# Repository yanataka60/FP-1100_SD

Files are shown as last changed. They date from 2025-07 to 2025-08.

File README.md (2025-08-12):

# CASIO FP-1100にSD-Cardとのロード、セーブ機能

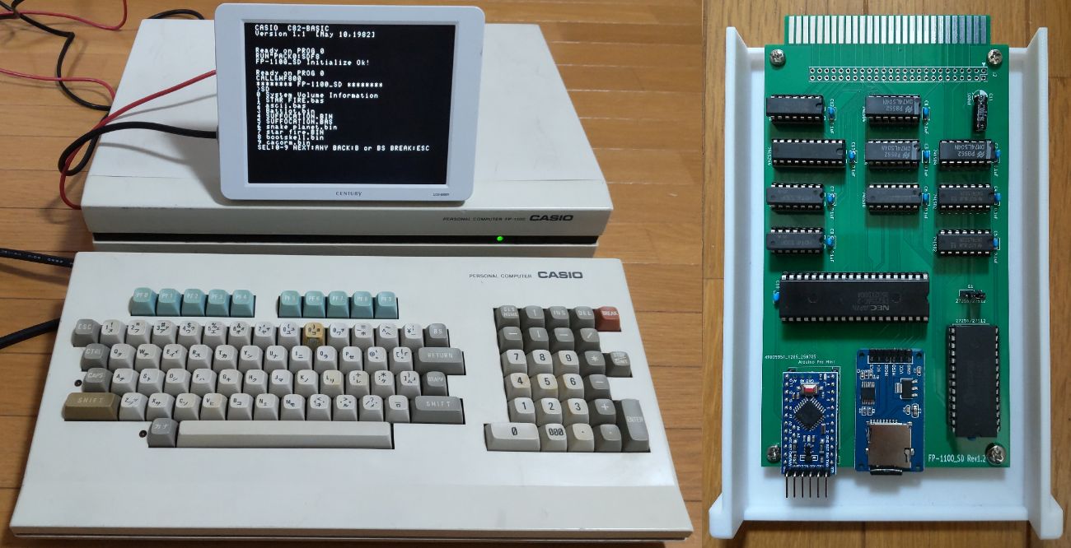
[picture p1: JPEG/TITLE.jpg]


　CASIO FP-1100でCMTの代わりにSD-CARDからロード、セーブを実現するものです。

　FP-1000は所有していないので試していませんが、動作すると思います。

　SDから読み込めるCMTのファイル形式はEMUで一般的なWAV、CASには対応していません。bugfire2009さんのDumpListEditorを使ってバイナリ形式に変換したものを使います。

　機械語 -> 各モデル固有ヘッダ付きBINファイル、拡張子は.bin

　BASIC -> BASファイル、拡張子は.bas

　CMTからの読み込み実行に数分掛かっていたゲームも数十秒で実行できます。

　ただし、CMT用プログラムのすべてがSD対応となるわけではありません。特に市販ゲームはCMT読み込みに独自ルーチンを使っているものもあるため、SD対応は不明です。

　なお、Arduino、ROMへ書き込むための機器が別途必要となります。

## 回路図
　KiCadフォルダ内のFP-1100_SD.PDFを参照してください。

[回路図](https://github.com/yanataka60/FP-1100_SD/blob/main/Kicad/FP-1100_SD.PDF)

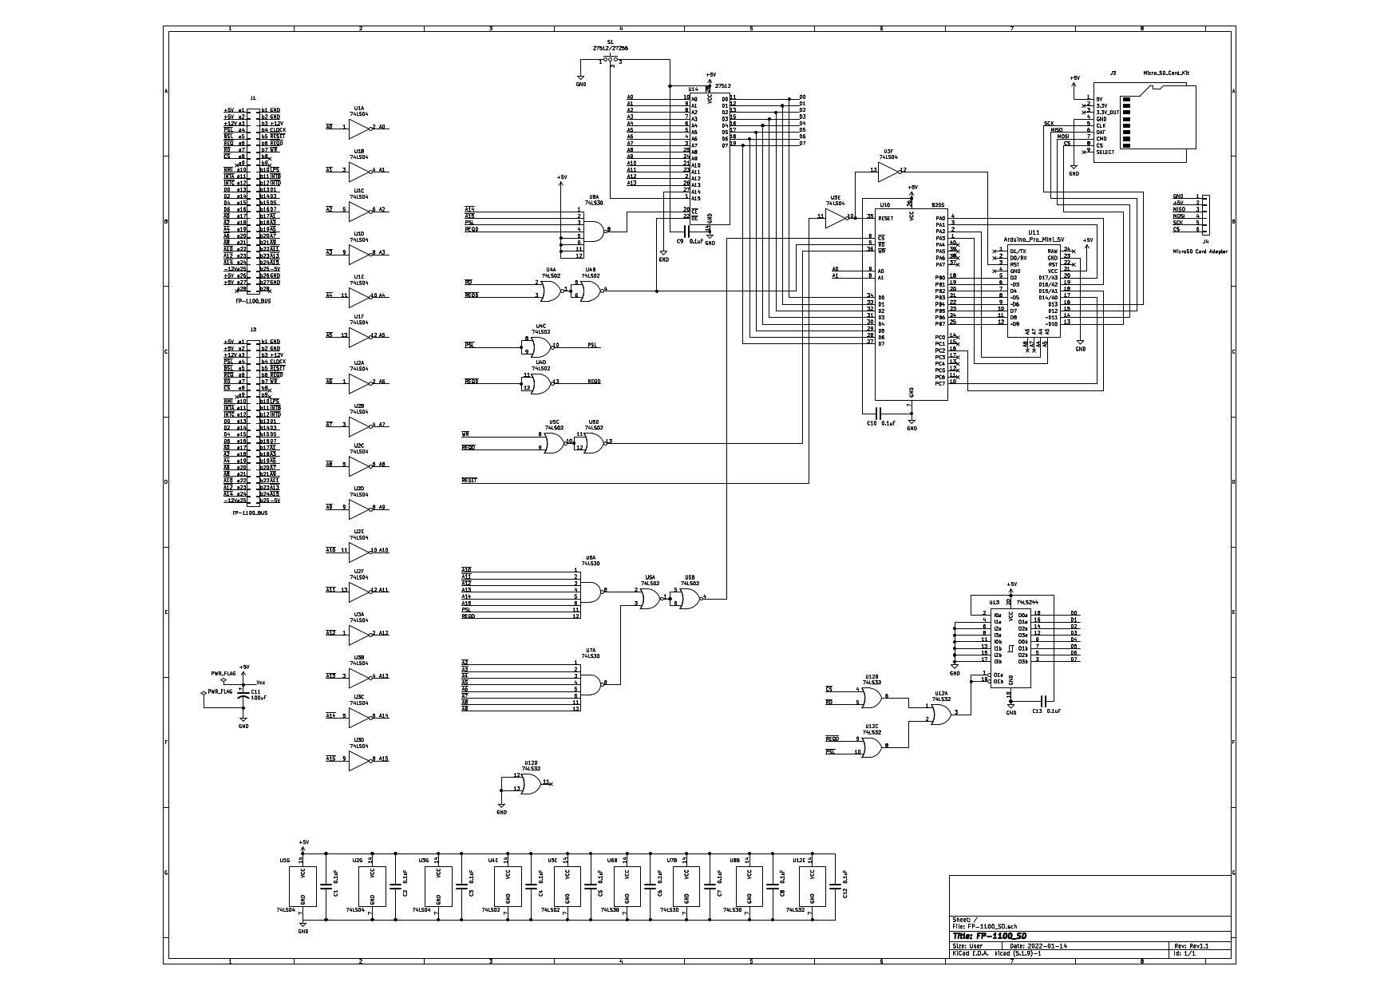
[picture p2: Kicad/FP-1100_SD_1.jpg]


## 部品
|番号|品名|数量|備考|
| --- | --- | --- | --- |
||J3,J4のいずれか|||
|J3|Micro_SD_Card_Kit|1|秋月電子通商 AE-microSD-LLCNV (注1)|
|J4|MicroSD Card Adapter|1|Arduino等に使われる5V電源に対応したもの(注2)|
|U1-U3|74LS04|3||
|U4-U5|74LS02|2||
|U6-U8|74LS30|3||
|U10|8255|1||
|U11|Arduino_Pro_Mini_5V|1|Atmega328版を使用 168版は不可。(注3)|
|U12|74LS32|1||
|U13|74LS244|1||
|U14|ROM 27256/29C256又は27512/27C512相当品|1|入手しやすいものでOK、28C256は不可|
|C1-C10,C12,C13|積層セラミックコンデンサ 0.1uF|12||
|C11|電解コンデンサ 16v100uF|1||
|S1|3Pin ピンヘッダーとジャンパーピン又は3Pスライドスイッチ|1|秋月電子通商 SS12D01G4など|

### 注1)秋月電子通商　AE-microSD-LLCNVのJ1ジャンパはショートしてください。

### 注2)MicroSD Card Adapterを使う場合

J4に取り付けます。

MicroSD Card Adapterについているピンヘッダを除去してハンダ付けするのが一番確実ですが、J2の穴にMicroSD Card Adapterをぴったりと押しつけ、裏から多めにハンダを流し込むことでハンダ付けをする方法もあります。なお、この方法の時にはしっかりハンダ付けが出来たかテスターで導通を確認しておいた方が安心です。

ハンダ付けに自信のない方はJ1の秋月電子通商　AE-microSD-LLCNVをお使いください。AE-microSD-LLCNVならパワーLED、アクセスLEDが付いています。

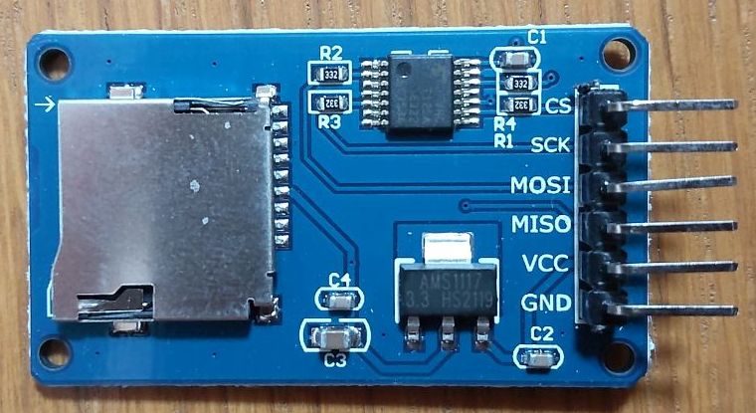
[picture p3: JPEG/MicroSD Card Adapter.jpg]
MicroSD Card Adapter1


### 注3)Arduino Pro MiniはA4、A5ピンも使っています。

## FP-1100_SDをスロットに入れずに外付けとして使いたい場合のみ
　J2ピンヘッダを取り付けます。また、スロットからケーブルを引き出す基板が必要ですのでFP-1100_SD基板がもう一枚必要です。

|番号|品名|数量|備考|
| --- | --- | --- | --- |
|J2|2x25Pinコネクタ|1|秋月電子通商 PH-2x40SGなど|
||FP-1100_SD基板|1||
||2.54mmピッチ2x25Pinフラットケーブル|1|FP-1100の拡張スロットは2x28Pinですが、2x25Pinが使えます|

## 取り付け
　FP-1100本体後ろのスロットに挿入します。

　スロットにガイド等が無いためスロットの奥を覗き込みながら挿入します。

　基板の下に10～12mmの隙間が空くようにネジやスペーサーなどを取り付け、カードエッジコネクタと高さを合わせると挿入しやすくなります。

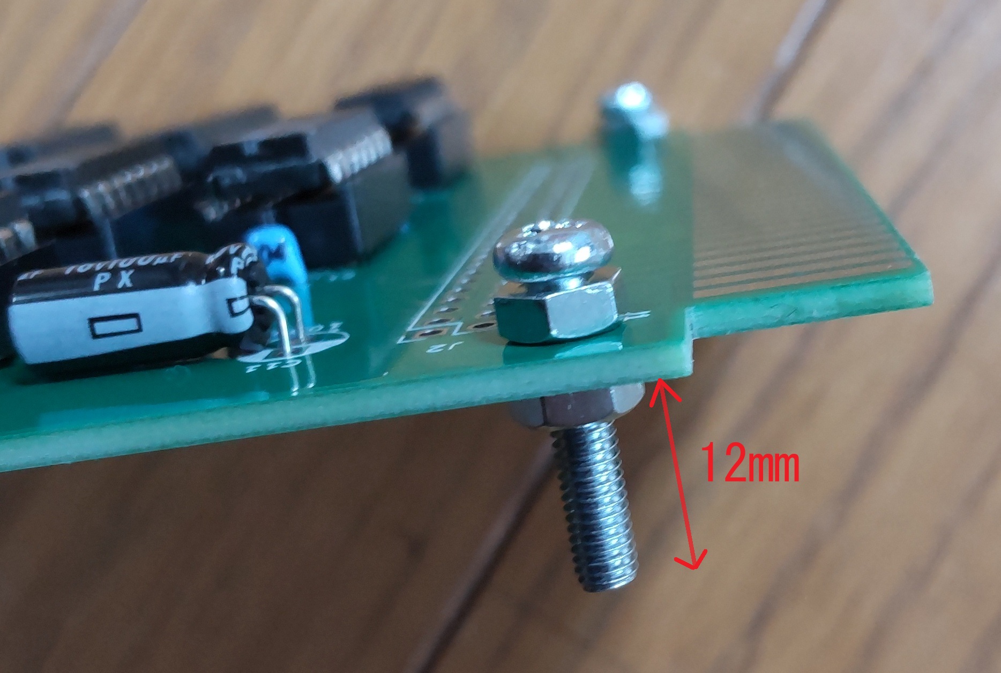
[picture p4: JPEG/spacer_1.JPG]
Spacer1


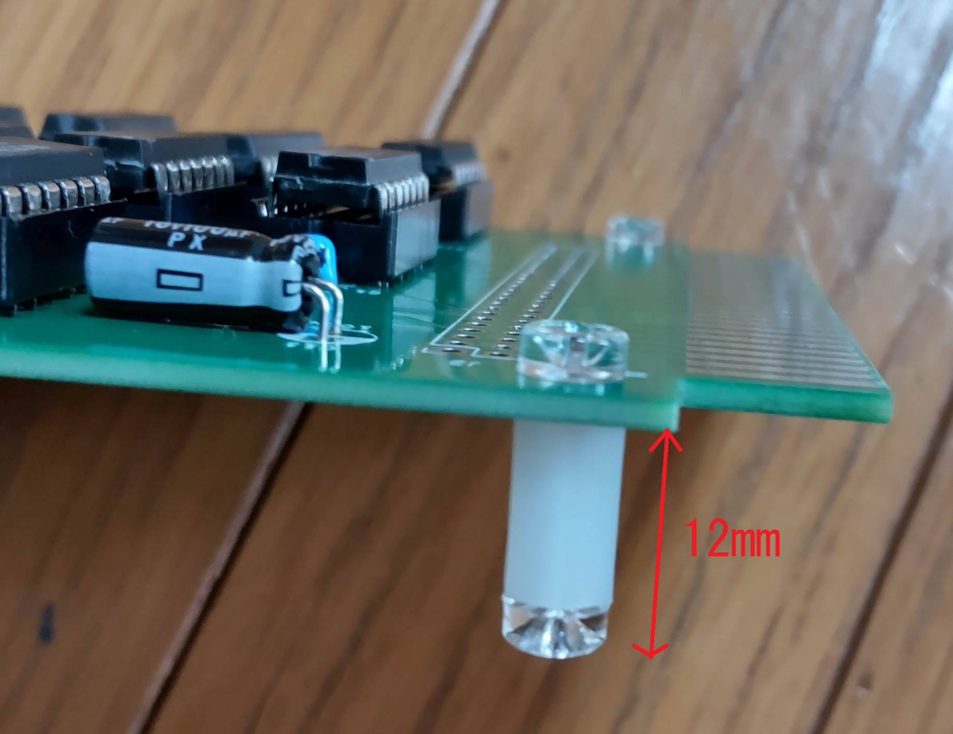
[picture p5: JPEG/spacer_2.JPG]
Spacer2


　外すときには基板のねじ穴にドライバー等を差し込んでひねるようにすれば取り外しやすいです。

　STLフォルダに基板を載せられるトレイの3Dデータを置いたので出力して使うと抜き差しが楽になります。

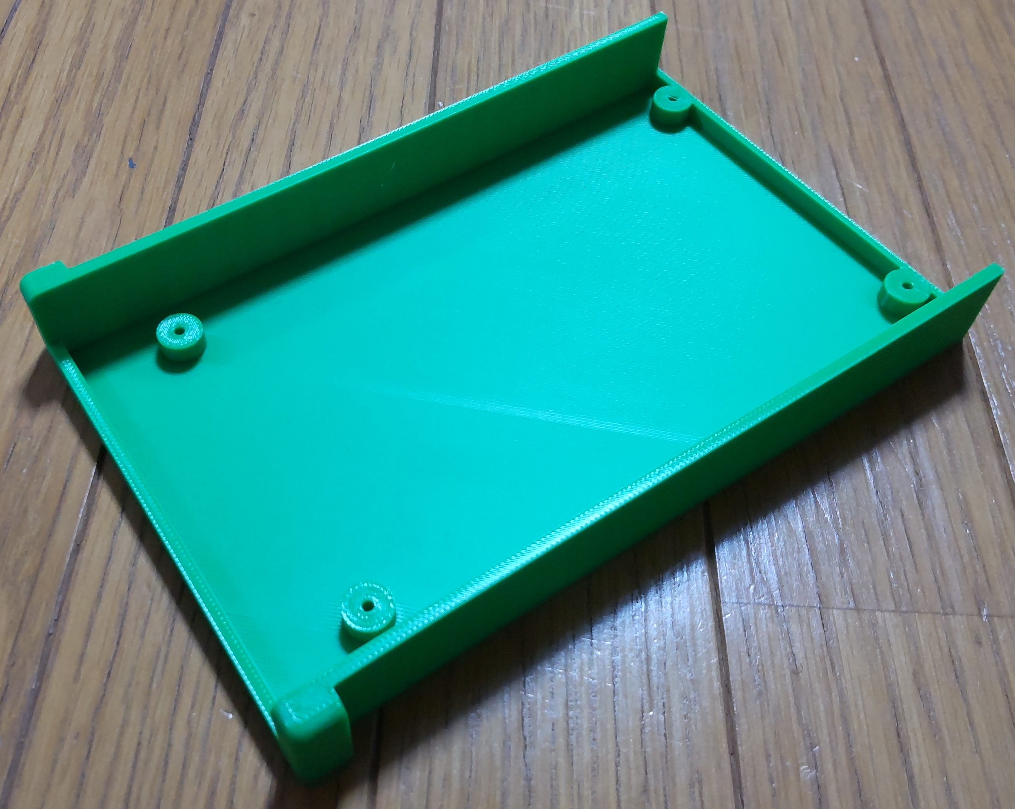
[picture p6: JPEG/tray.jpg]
Tray


　標準はSLOT0ですが、SLOT1で使うときは起動後にSLコマンドでSLOT1を指定してください。

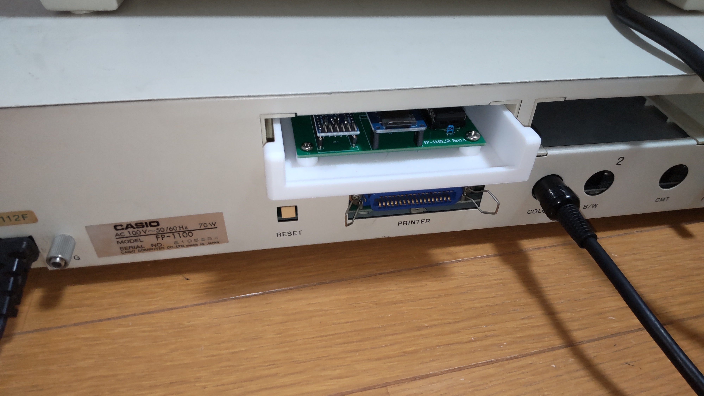
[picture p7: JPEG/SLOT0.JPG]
SLOT0

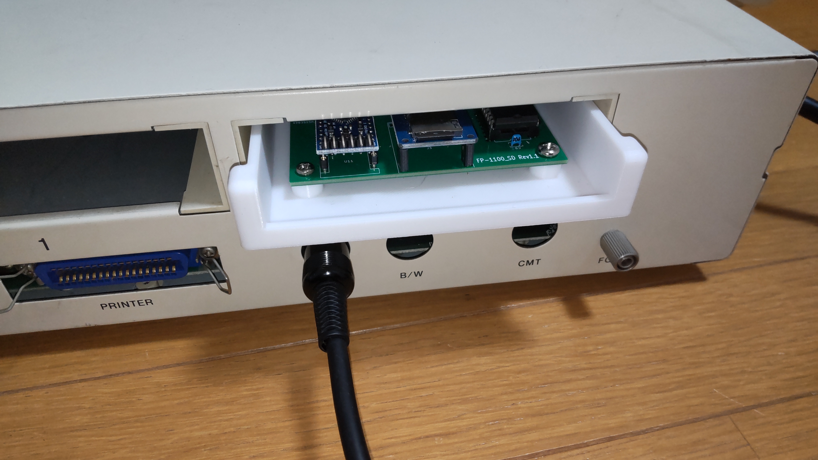
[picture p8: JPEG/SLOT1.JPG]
SLOT1


### FP-1100_SDをスロットに入れずに外付けとしてフラットケーブルによる接続
　J2コネクタ1Pinを示す基板上の△印にフラットケーブルの1Pinを示す△印を合わせてフラットケーブルを挿入します。

　FP-1100の拡張スロットは2x28Pinですが、2x25Pinフラットケーブルが使えます。

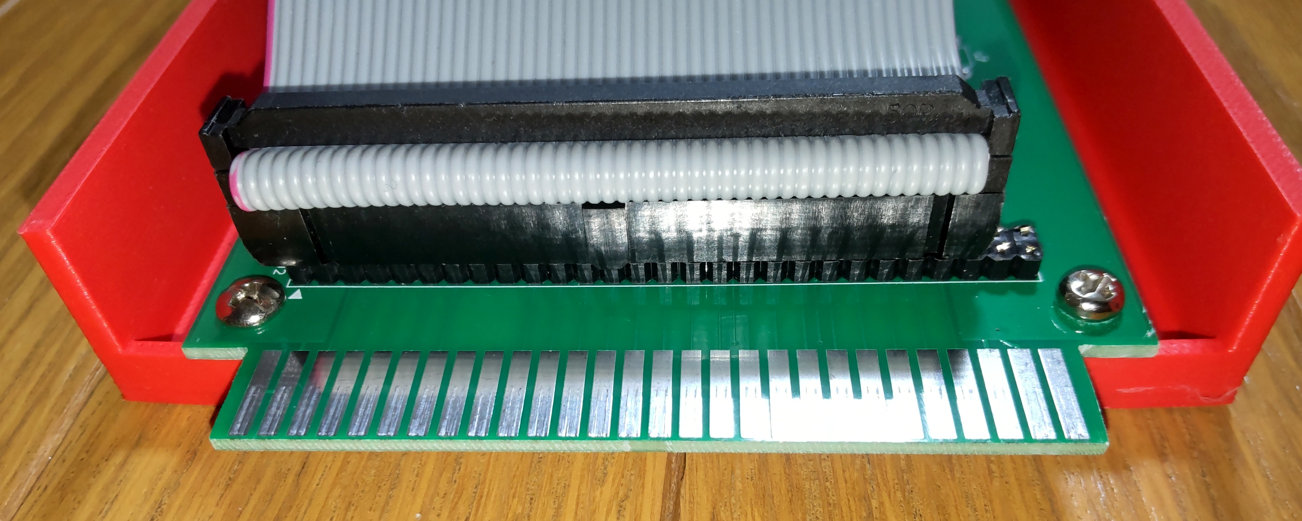
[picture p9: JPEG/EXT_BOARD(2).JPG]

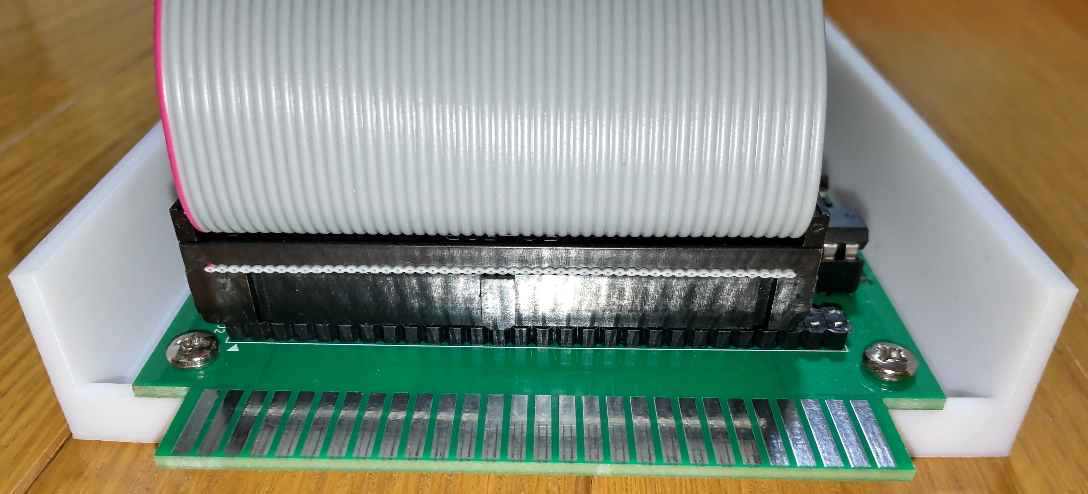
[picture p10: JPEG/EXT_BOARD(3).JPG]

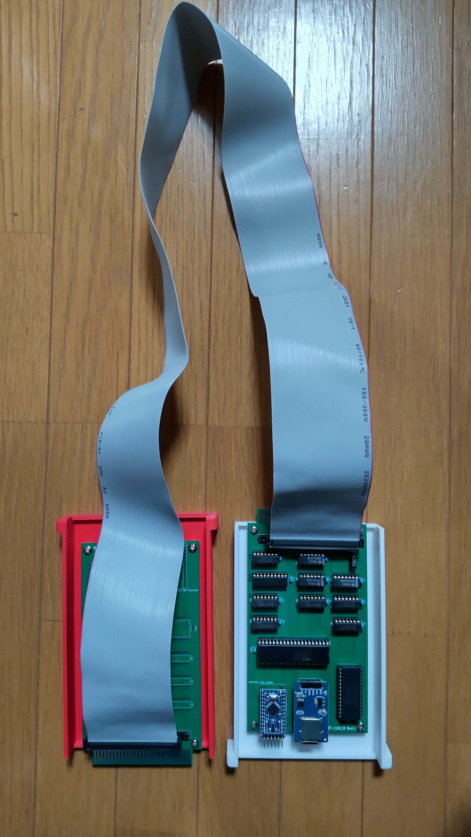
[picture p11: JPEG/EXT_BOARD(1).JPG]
Flat cable1


## ROMへの書込み
　Z80フォルダ内のRAMPACK1.binをROMライター(TL866II Plus等)を使って27256又は27512に書き込みます。

　実際に使用しているのは16KByte分(16Kx8)です。

　FP-1100_SDのROMはFP-1100からはRAMパックとして扱われます。(FP-1100から書き込みはできません。)

　本物のRAMパック、ROMパックともハードウェア的には併用可能なはずですが、現物を所有していないため動作検証は行っていません。

### 2025.8.12 FP-1100_SD以外のPACKをSLOTに挿入して同時に使用している場合にSDにアクセスできなくなるバグを発見しました。
　現在バージョンは修正済みですが、旧バージョンROMの方はZ80フォルダ内のPATCH.binをSDにコピーし、SDF8(SDE8)を実行直後にSDアクセスメニューに入り、読み込み実行すれば修正されます。

## RAMPACK1.binに登録されているファイル
　RAMPACK1.binに登録されているファイルは次の4つになります。

|ファイル名|種類|
| --- | --- |
|SDF8|BASIC|
|SDE8|BASIC|
|BOOTF8|BINARY|
|BOOTE8|BINARY|

　また、RAMPACK1.binへのファイル登録はTAKEDAさんのEMU eFP-1100で行っており、fp1100.exeと同じフォルダに置くことでeFP-1100からは「PACK0:」として読み書き出来ます。

## Arduinoプログラム
　Arduino IDEを使ってArduinoフォルダのFP-1100_SDフォルダ内FP-1100_SD.inoを書き込みます。

　SdFatライブラリを使用しているのでArduino IDEメニューのライブラリの管理からライブラリマネージャを立ち上げて「SdFat」をインストールしてください。

　「SdFat」で検索すれば見つかります。「SdFat」と「SdFat - Adafruit Fork」が見つかりますが「SdFat」のほうを使っています。

注)Arduinoを基板に直付けしている場合、Arduinoプログラムを書き込むときは、FP-1100本体とは接続を外し、U3 74LS04を外したうえで書き込んでください。

## SD-CARD
　出来れば8GB以下のSDカードを用意してください。

　ArduinoのSdFatライブラリは、SD規格(最大2GB)、SDHC規格(2GB～32GB)に対応していますが、SDXC規格(32GB～2TB)には対応していません。

　また、SDHC規格のSDカードであっても32GB、16GBは相性により動作しないものがあるようです。

　FAT16又はFAT32が認識できます。NTFSは認識できません。

## 操作方法
　起動直後に「RUN"PACK0:SDF8"」を実行してSDアクセスルーチンの読込、初期化の実行を行います。

　SDアクセスルーチンをF800h～FFFChに読み込む「SDF8」とE800h～EFF2hに読み込む「SDE8」の２種類を用意していますが、基本的には「SDF8」を使い、F000h～FFFFhへプログラムをロードしたいときだけ「SDE8」を使ってください。

　「SDE8」を使うときは、「RUN"PACK0:SDE8"」を実行します。

　SDアクセスメニューを表示するにはCALL&HF800(CALL&HE800)を実行しますが、F7ファンクションキーに登録してありますのでF7ファンクションキーを押しても大丈夫です。

#### 扱えるファイル
bugfire2009さんのDumpListEditorを使ってバイナリ形式に変換したものを使います。

扱う機種をFP-1100に変更したうえで変換します。

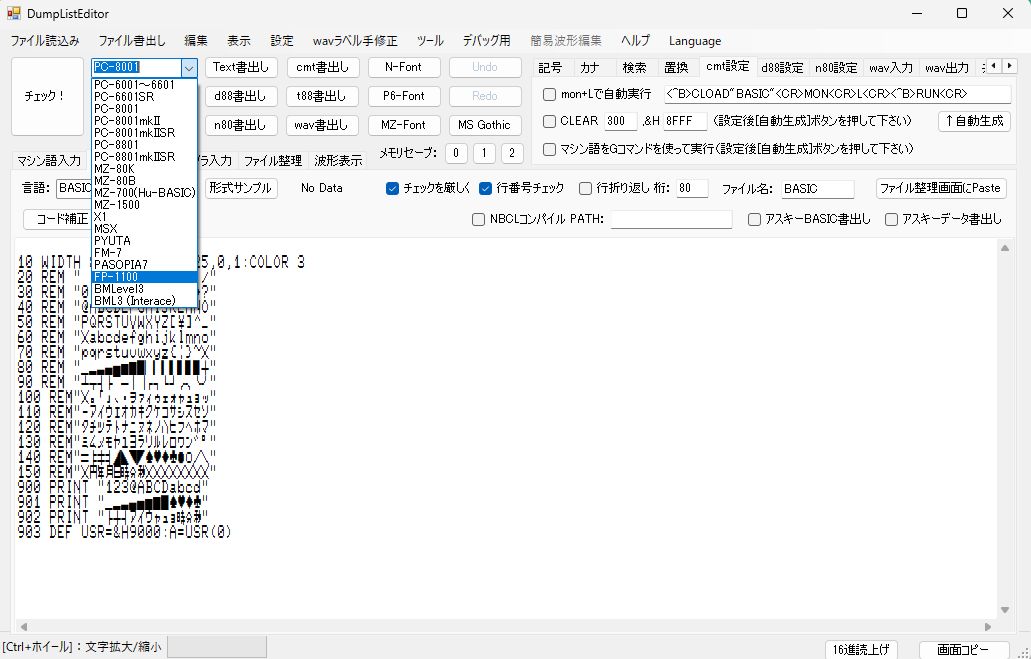
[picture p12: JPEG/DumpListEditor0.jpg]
DumpListEditor0


##### 機械語 -> 「BINファイル書出し(各モデル固有ヘッダ付き)」で保存、拡張子は.bin

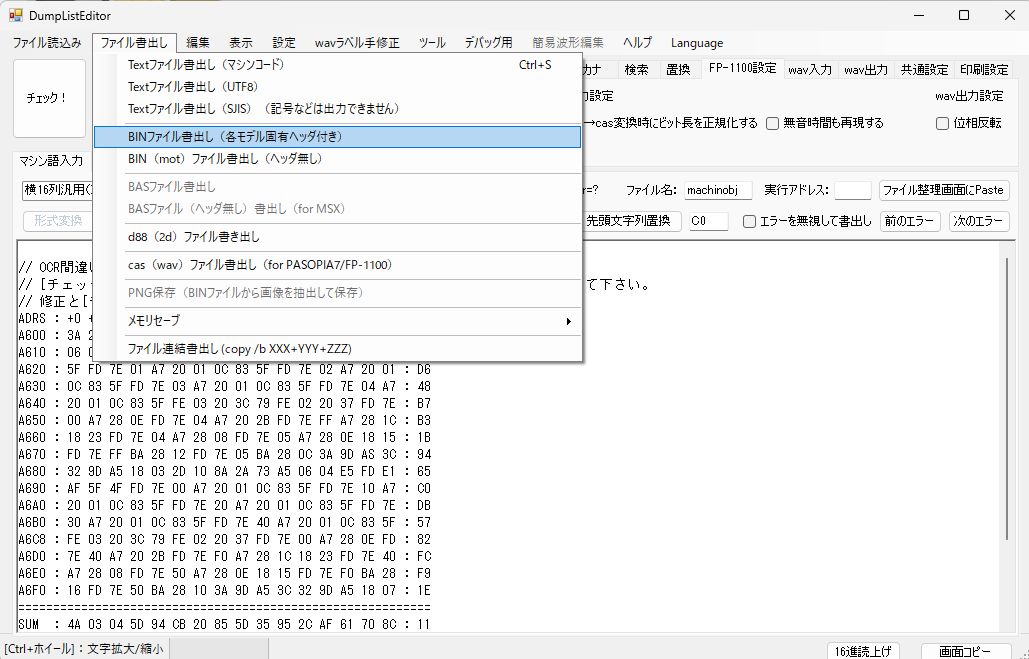
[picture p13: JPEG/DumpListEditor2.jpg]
DumpListEditor1


##### BASIC -> 「BASファイル書出し」で保存、拡張子は.bas

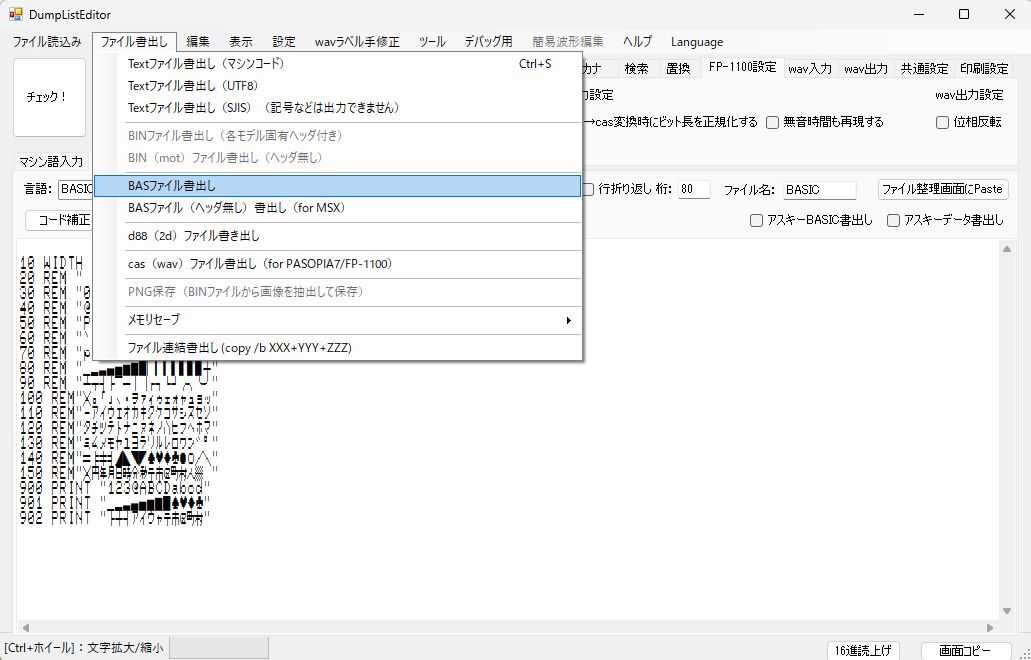
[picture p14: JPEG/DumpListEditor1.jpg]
DumpListEditor2


### コマンド
　コマンド入力時にBSキー又は左カーソルキーで直前に入力した文字を訂正できます。

　CLR、HOME、上・下・右カーソルキーは画面が乱れるだけで入力文字の訂正は出来ません。

#### 2025.8.12 BASICプログラムを実行した後にSDアクセスメニューを実行するとコマンドを入力できなくなる場合があるようです。
　原因を調査中ですが、回避方法は以下になります。

　コマンドが入力できない状態の時はBREAKキーを押すことでBASICに戻れます。

　LISTコマンドを一回実行してください。途中でBREAKしても大丈夫です。これでSDアクセスメニューを実行しても入力できる状態に戻ります。

#### SD[RETURN]又はSD 文字列[RETURN]
　文字列を入力せずにSD[RETURN]のみ入力するとSD-CARDルートディレクトリにあるファイルの一覧を表示します。

　文字列を付けて入力すればSD-CARDルートディレクトリにあるその文字列から始まるファイルの一覧を表示します。
　10件表示したところで指示待ちになるのでESCキーで終了、Bキー又はBSキーで前の10件に戻ります。それ以外のキーで次の10件を表示します。

　LOADしたいファイルを見つけたら左端の数字のキーを押せばLOADされます。

　BASICプログラムか、機械語プログラムかは自動で判断します。

　なお、F7FFh以降へ機械語プログラムがLOADされた場合、次の三段階の挙動となります。

　1)～F9ACh:機械語プログラムをLOAD後は、SM,SB,SLコマンドが使用できなくなります。LM,LG,LB,SD,G,Q,Bコマンドは使用できます。

　2)～FDDEh:機械語プログラムをLOAD後は、G,Q,Bのみ使えます。SD,LMコマンドでLOADした後、Gコマンドでの実行は可能です。

　3)～FF59h:機械語プログラムをLOAD後は、すべてのコマンドが使えません。FDDFh以降までLOADされた場合は強制的に実行番地にジャンプを試みます。

　表示される順番は、登録順となりファイル名アルファベッド順などのソートした順で表示することはできません。

##### 例)
　　SD[RETURN]

　　SD S[RETURN]

　　SD SP[RETURN]

#### LM DOSファイル名[RETURN]
　指定したDOSフィル名の機械語プログラムをSD-CARDからLOADします。

　拡張子が「bin」であるファイルだけが対象でファイル名の最後が「.BIN」でない場合には自動的に付加されます。
　読み込める機械語プログラムの範囲は通常F7FFhまでとなります。F000h～FFFFhへ機械語プログラムをLOADしたいときは「SDE8」を使用してください。

　なお、F7FFh以降へ機械語プログラムがLOADされた場合、次の三段階の挙動となります。

　1)～F9ACh:機械語プログラムをLOAD後は、SM,SB,SLコマンドが使用できなくなります。LM,LG,LB,SD,G,Q,Bコマンドは使用できます。

　2)～FDDEh:機械語プログラムをLOAD後は、G,Q,Bのみ使えます。SD,LMコマンドでLOADした後、Gコマンドでの実行は可能です。

　3)～FF59h:機械語プログラムをLOAD後は、すべてのコマンドが使えません。FDDFh以降までLOADされた場合は強制的に実行番地にジャンプを試みます。

##### 例)
　　LM TEST[RETURN] -> DOSファイル名「TEST.BIN」を読み込みます。

　　LM TEST.BIN[RETURN] -> DOSファイル名「TEST.BIN」を読み込みます。

　　LM TEST.BAS[RETURN] -> DOSファイル名「TEST.BAS.BIN」を読み込みます。

#### LG DOSファイル名[RETURN]
　指定したDOSフィル名の機械語プログラムをSD-CARDからLOADした後、実行開始アドレスへジャンプします。

　LOAD後そのまま実行するのでFF64hまでLOADしても大丈夫です。

　LOADした後、実行開始アドレスへジャンプする以外はLMコマンドと同じです。

#### LB DOSファイル名[RETURN]
　現在選択しているPROGエリアに指定したDOSフィル名のBASICプログラムをSD-CARDからLOADします。

　LOADするPROGエリアを切り替えたい場合にはSDメニューに入る前に切り替えておいてください。

　拡張子が「bas」であるファイルだけが対象でファイル名の最後が「.BAS」でない場合には自動的に付加されます。

##### 例)
　　LB TEST[RETURN] -> DOSファイル名「TEST.BAS」を読み込みます。

　　LB TEST.BAS[RETURN] -> DOSファイル名「TEST.BAS」を読み込みます。

　　LB TEST.BIN[RETURN] -> DOSファイル名「TEST.BIN.BAS」を読み込みます。

#### SM XXXX,YYYY,ZZZZ,DOSファイル名[RETURN]　(XXXX,YYYY,ZZZZは16進数4桁を表す文字列)
　XXXX番地からYYYY番地までの機械語プログラムを実行番地ZZZZとして指定したDOSフィル名でSD-CARDにSAVEします。

　拡張子の指定「.bin」は省略することが出来、ファイル名の最後が「.BIN」でない場合には自動的に付加されます。

##### 例)
　　SM B000,BFFF,B000,TEST[RETURN] -> B000h～BFFFhまでを実行番地B000hとしてDOSファイル名「TEST.BIN」でSAVEします。

　　SM B000,BFFF,B000,TEST.BIN[RETURN] -> B000h～BFFFhまでを実行番地B000hとしてDOSファイル名「TEST.BIN」でSAVEします。

　　SM B000,BFFF,B000,TEST.BAS[RETURN] -> B000h～BFFFhまでを実行番地B000hとしてDOSファイル名「TEST.BAS.BIN」でSAVEします。

#### SB DOSファイル名[RETURN]
　現在選択しているPROGエリアのBASICプログラムを指定したDOSフィル名でSD-CARDにSAVEします。

　SAVEするPROGエリアを切り替えたい場合にはSDメニューに入る前に切り替えておいてください。

　拡張子の指定「.bas」は省略することが出来、ファイル名の最後が「.BAS」でない場合には自動的に付加されます。

##### 例)
　　SB TEST[RETURN] -> DOSファイル名「TEST.BAS」でSAVEします。

　　SB TEST.BAS[RETURN] -> DOSファイル名「TEST.BAS」でSAVEします。

　　SB TEST.BIN[RETURN] -> DOSファイル名「TEST.BIN.BAS」でSAVEします。

#### G[RETURN]又はG 16進数4桁[RETURN]
　Gだけの場合は、直前にLOADした機械語プログラムの実行番地へジャンプします。

　16進数4桁を指定した場合は16進数4桁が表すアドレスにジャンプします。

　Gの後ろに空白があっても無くても構いません。

#### SL[RETURN]
　入力待ちになるので0又は1キーでSLOT番号を入力します。0,1以外を入力した場合は再度入力待ちになります。

　FP-1100_SD初期化直後はSLOT0になっていますのでFP-1100_SDをSLOT1に挿入して使う場合には切り替えてください。

#### B[RETURN]又はQ[RETURN]
　BASICに復帰します。

### BASICプログラム中から機械語プログラムをLOADする
　BASICプログラム中に「CALL &HF803:REM ファイル名」と記述することで機械語プログラムをLOAD出来ます。

　ファイル名はSDカードに保存されているファイル名です。拡張子はつけてもつけなくても構いません。

　LOAD出来るのはF7FFhまでです。(clear文を修正すれば最大FA3Fhまで可能です)

##### 例)

30 CALL &HF803:REM TRAFFIC CONTROL.bin

## 操作上の注意
　電源を入れたままSD-CARDの抜き差しをする場合又は「SD-CARD INITIALIZE ERROR」と表示されたときは、SD-CARDを挿入後、SD、LM、LBコマンド等でSD-CARDに3回ほどアクセスすれば復旧します。

　SD-CARDの抜き差しは電源を切った状態で行うほうがより確実です。

## 謝辞
　基板の作成に当たり以下のデータを使わせていただきました。ありがとうございました。

　Arduino Pro Mini

　　https://github.com/g200kg/kicad-lib-arduino

　AE-microSD-LLCNV

　　https://github.com/kuninet/PC-8001-SD-8kRAM

　FP-1100の資料を提供いただいたPro Nyan@Nyan4Pro様、ありがとうございました。

## 追記
2025.7.11 SDコマンドでF9A9hを超えて機械語プログラムをLOADした時の挙動にバグがあったので修正。FDDAhを超えるLOADの場合は強制的に実行番地へジャンプすることに修正。

2025.7.13 BASICプログラムLOAD時のAREA OVERエラー表示のバグを修正。

2025.7.30 BASICプログラム未入力でSAVEしようとしたときに'Basic Program Nothing!'と表示した後Arduinoが応答しなくなるバグを修正。それに伴ってF7FFh以降へ機械語プログラムがLOADされた場合の限界アドレスが変動。

2025.8.6 BASICプログラム中から機械語プログラムをLOADする方法の記述が抜けていたので追記。

2025.8.12 FP-1100_SD以外のPACKを同時に使うときにはSLOTを再指定する必要があったので修正。BASICプログラムを実行した後にSDアクセスメニューを実行するとコマンドを入力できなくなる場合の回避方法を記述。

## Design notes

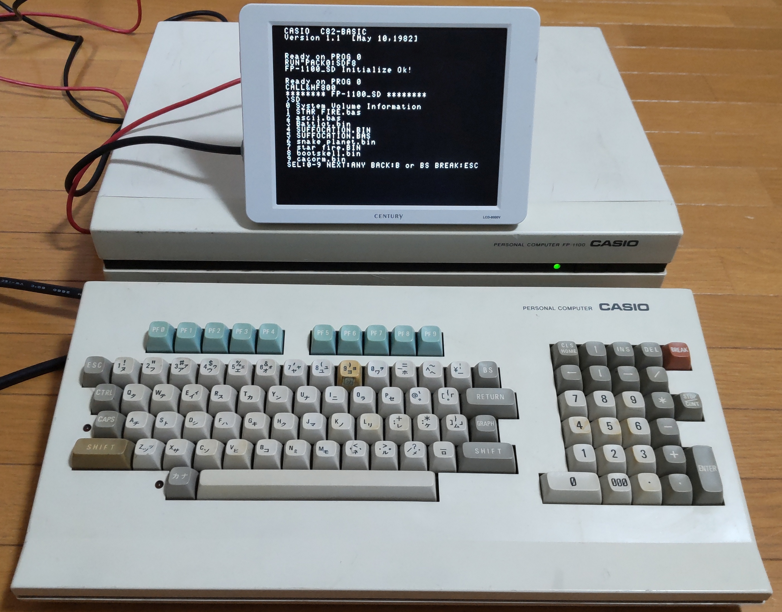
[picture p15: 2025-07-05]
JPEG/FP-1100.JPG

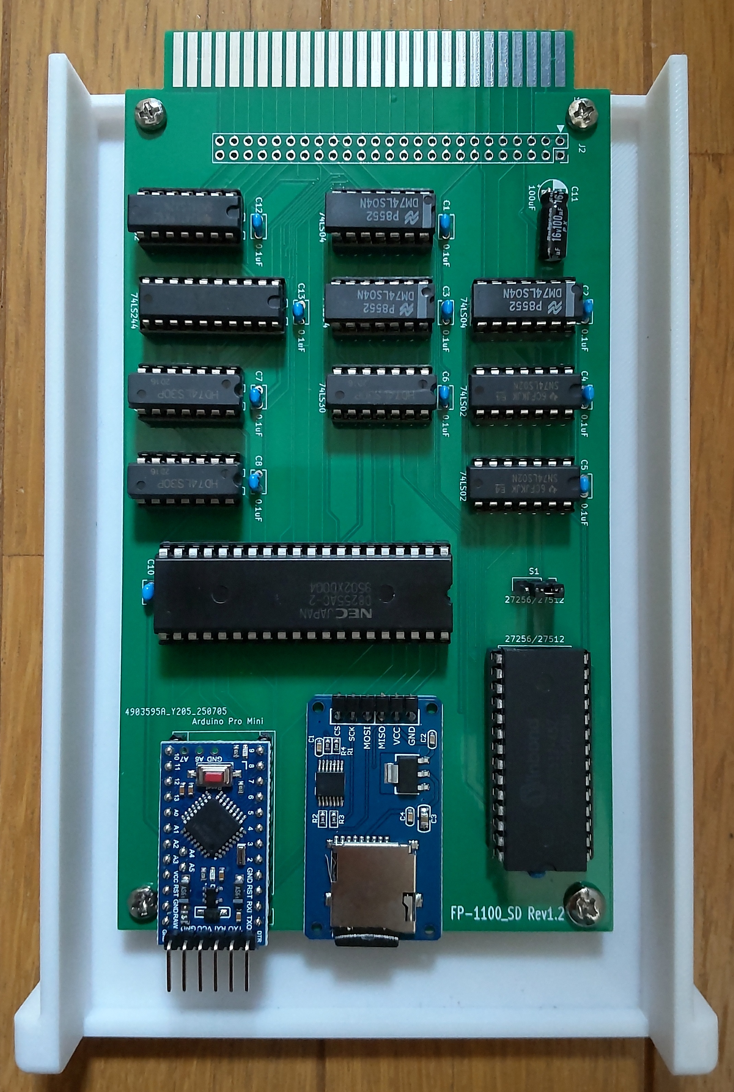
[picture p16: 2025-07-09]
JPEG/FP-1100_SD.JPG

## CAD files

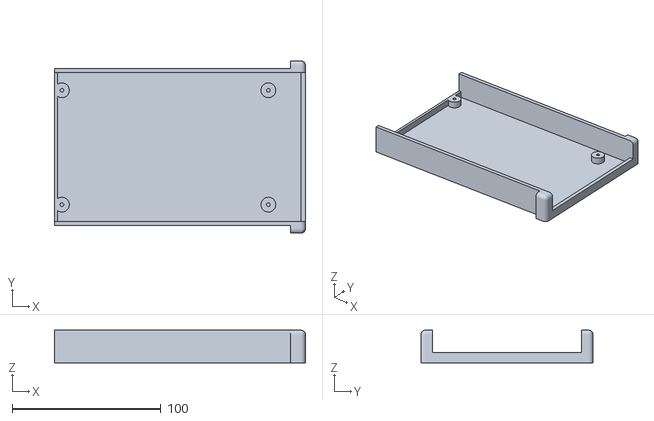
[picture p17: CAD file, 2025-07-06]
STL/FP-1100_SD tray.stl
169.0 x 116.0 x 22.0

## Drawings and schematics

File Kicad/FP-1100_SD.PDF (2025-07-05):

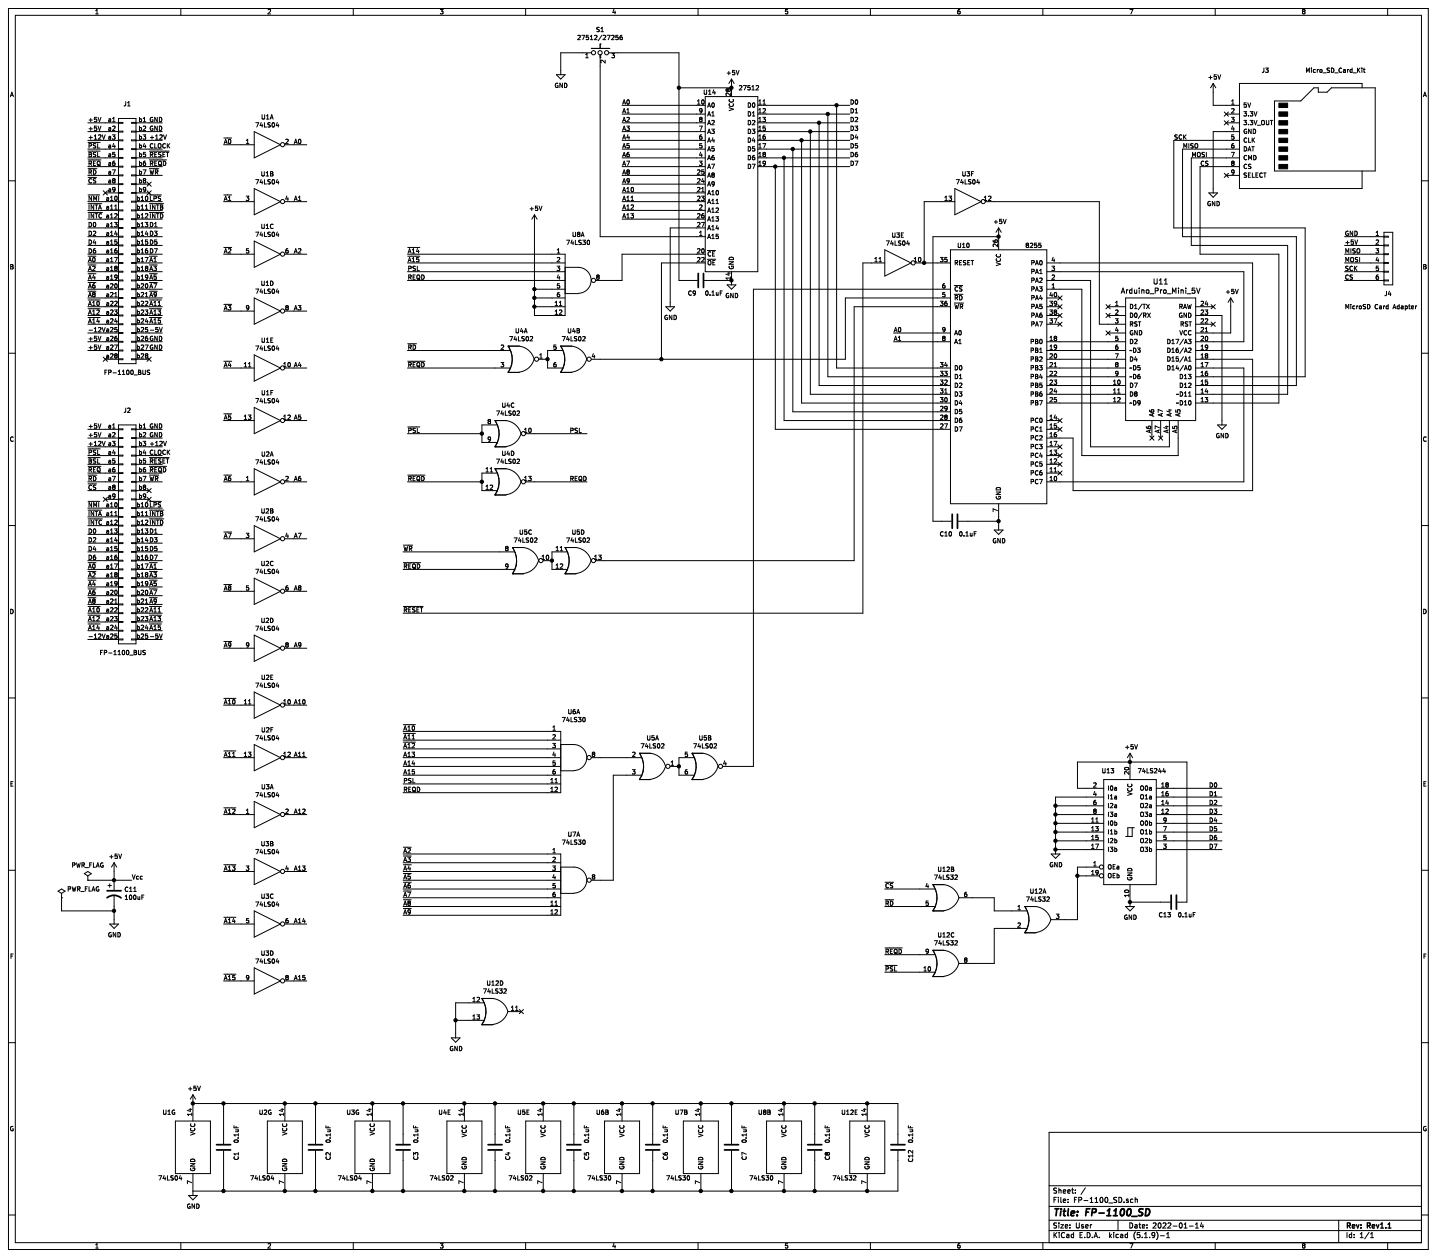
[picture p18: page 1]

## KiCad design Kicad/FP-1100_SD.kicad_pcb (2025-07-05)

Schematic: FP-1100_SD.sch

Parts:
C1, C2, C3, C4, C5, C6, C7, C8, C9, C10, C12, C13: 0.1uF; C_Rect_L4.0mm_W2.5mm_P2.50mm
C11: 100uF; CP_Radial_D5.0mm_P2.50mm
J1: FP-1100_BUS; BUS_56Pin
J2: FP-1100_BUS; PinSocket_2x25_P2.54mm_Vertical
J3: Micro_SD_Card_Kit; AE-microSD-LLCNV
J4: MicroSD Card Adapter; PinHeader_1x06_P2.54mm_Vertical
S1: 27512/27256; PinHeader_1x03_P2.54mm_Vertical
U1, U2, U3: 74LS04; DIP-14_W7.62mm_LongPads
U4, U5: 74LS02; DIP-14_W7.62mm_LongPads
U6, U7, U8: 74LS30; DIP-14_W7.62mm_LongPads
U10: 8255; DIP-40_W15.24mm_LongPads
U11: Arduino_Pro_Mini_5V; Arduino_Pro_Mini
U12: 74LS32; DIP-14_W7.62mm_LongPads
U13: 74LS244; DIP-20_W7.62mm_LongPads
U14: 27512; DIP-28_W15.24mm

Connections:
+5V: C1.2, C2.2, C3.2, C4.2, C5.2, C6.2, C7.2, C8.2, C9.1, C10.1, C11.1, C12.2, C13.2, J1.a1, J1.a2, J1.a26, J1.a27, J2.a1, J2.a2, J3.1 (5V), J4.2, S1.3, U1.14 (VCC), U2.14 (VCC), U3.14 (VCC), U4.14 (VCC), U5.14 (VCC), U6.14 (VCC), U7.14 (VCC), U8.5, U8.6, U8.11, U8.12, U8.14 (VCC), U10.26 (VCC), U11.21 (VCC), U12.14 (VCC), U13.2 (I0a), U13.20 (VCC), U14.28 (VCC)
/+12V: J1.a3, J1.b3, J2.a3, J2.b3
/-5V: J1.b25, J2.b25
/-12V: J1.a25, J2.a25
/A0: U1.2, U10.9 (A0), U14.10 (A0)
/A1: U1.4, U10.8 (A1), U14.9 (A1)
/A2: U1.6, U14.8 (A2)
/A3: U1.8, U14.7 (A3)
/A4: U1.10, U14.6 (A4)
/A5: U1.12, U14.5 (A5)
/A6: U2.2, U14.4 (A6)
/A7: U2.4, U14.3 (A7)
/A8: U2.6, U14.25 (A8)
/A9: U2.8, U14.24 (A9)
/A10: U2.10, U14.21 (A10)
/A11: U2.12, U14.23 (A11)
/A12: U3.2, U14.2 (A12)
/A13: U3.4, U6.4, U14.26 (A13)
/A14: U3.6, U6.5
/A15: U3.8, U6.6
/CLOCK: J1.b4, J2.b4
/CS: J3.8 (CS), J4.6, U11.13 (~~D10)
/D0: J1.a13, J2.a13, U10.34 (D0), U13.18 (O0a), U14.11 (D0)
/D1: J1.b13, J2.b13, U10.33 (D1), U13.16 (O1a), U14.12 (D1)
/D2: J1.a14, J2.a14, U10.32 (D2), U13.14 (O2a), U14.13 (D2)
/D3: J1.b14, J2.b14, U10.31 (D3), U13.12 (O3a), U14.15 (D3)
/D4: J1.a15, J2.a15, U10.30 (D4), U13.9 (O0b), U14.16 (D4)
/D5: J1.b15, J2.b15, U10.29 (D5), U13.7 (O1b), U14.17 (D5)
/D6: J1.a16, J2.a16, U10.28 (D6), U13.5 (O2b), U14.18 (D6)
/D7: J1.b16, J2.b16, U10.27 (D7), U13.3 (O3b), U14.19 (D7)
/MISO: J3.6 (DAT), J4.3, U11.15 (D12)
/MOSI: J3.7 (CMD), J4.4, U11.14 (~~D11)
/PSL: U4.10, U6.11, U8.3
/REQD: U4.13, U6.12, U8.4
/SCK: J3.5 (CLK), J4.5, U11.16 (D13)
/~A0: J1.a17, J2.a17, U1.1
/~A1: J1.b17, J2.b17, U1.3
/~A2: J1.a18, J2.a18, U1.5, U7.1
/~A3: J1.b18, J2.b18, U1.9, U7.2
/~A4: J1.a19, J2.a19, U1.11, U7.3
/~A5: J1.b19, J2.b19, U1.13, U7.4
/~A6: J1.a20, J2.a20, U2.1, U7.5
/~A7: J1.b20, J2.b20, U2.3, U7.6
/~A8: J1.a21, J2.a21, U2.5, U7.11
/~A9: J1.b21, J2.b21, U2.9, U7.12
/~A10: J1.a22, J2.a22, U2.11, U6.1
/~A11: J1.b22, J2.b22, U2.13, U6.2
/~A12: J1.a23, J2.a23, U3.1, U6.3
/~A13: J1.b23, J2.b23, U3.3
/~A14: J1.a24, J2.a24, U3.5, U8.1
/~A15: J1.b24, J2.b24, U3.9, U8.2
/~BSL: J1.a5, J2.a5
/~CS: J1.a8, J2.a8, U12.4
/~INTA: J1.a11, J2.a11
/~INTB: J1.b11, J2.b11
/~INTC: J1.a12, J2.a12
/~INTD: J1.b12, J2.b12
/~LPS: J1.b10, J2.b10
/~NMI: J1.a10, J2.a10
/~PSL: J1.a4, J2.a4, U4.8, U4.9, U12.10
/~RD: J1.a7, J2.a7, U4.2, U12.5
/~REQ: J1.a6, J2.a6
/~REQD: J1.b6, J2.b6, U4.3, U4.11, U4.12, U5.9, U12.9
/~RESET: J1.b5, J2.b5, U3.11
/~WR: J1.b7, J2.b7, U5.8
GND: C1.1, C2.1, C3.1, C4.1, C5.1, C6.1, C7.1, C8.1, C9.2, C10.2, C11.2, C12.1, C13.1, J1.b1, J1.b2, J1.b26, J1.b27, J2.b1, J2.b2, J3.4 (GND), J4.1, S1.1, U1.7 (GND), U2.7 (GND), U3.7 (GND), U4.7 (GND), U5.7 (GND), U6.7 (GND), U7.7 (GND), U8.7 (GND), U10.7 (GND), U11.23 (GND), U12.7 (GND), U12.12, U12.13, U13.4 (I1a), U13.6 (I2a), U13.8 (I3a), U13.10 (GND), U13.11 (I0b), U13.13 (I1b), U13.15 (I2b), U13.17 (I3b), U14.14 (GND), U14.27 (A14)
unnamed: S1.2, U14.1 (A15)
unnamed: U4.1, U4.5, U4.6
unnamed: U5.1, U5.5, U5.6
unnamed: U5.2, U6.8
unnamed: U5.3, U7.8
unnamed: U5.10, U5.11, U5.12
unnamed: U10.1 (PA3), U11.A5
unnamed: U10.2 (PA2), U11.A4
unnamed: U10.3 (PA1), U11.20 (D17/A3)
unnamed: U10.4 (PA0), U11.19 (D16/A2)
unnamed: U4.4, U10.5 (~RD~), U14.22 (~OE)
unnamed: U5.4, U10.6 (~CS~)
unnamed: U10.10 (PC7), U11.17 (D14/A0)
unnamed: U10.16 (PC2), U11.18 (D15/A1)
unnamed: U10.18 (PB0), U11.5 (D2)
unnamed: U10.19 (PB1), U11.6 (~~D3)
unnamed: U10.20 (PB2), U11.7 (D4)
unnamed: U10.21 (PB3), U11.8 (~~D5)
unnamed: U10.22 (PB4), U11.9 (~~D6)
unnamed: U10.23 (PB5), U11.10 (D7)
unnamed: U10.24 (PB6), U11.11 (D8)
unnamed: U10.25 (PB7), U11.12 (~~D9)
unnamed: U3.10, U3.13, U10.35 (RESET)
unnamed: U5.13, U10.36 (~WR~)
unnamed: U3.12, U11.3 (RST)
unnamed: U12.1, U12.6
unnamed: U12.2, U12.8
unnamed: U12.3, U13.1 (OEa), U13.19 (OEb)
unnamed: U8.8, U14.20 (~CE)

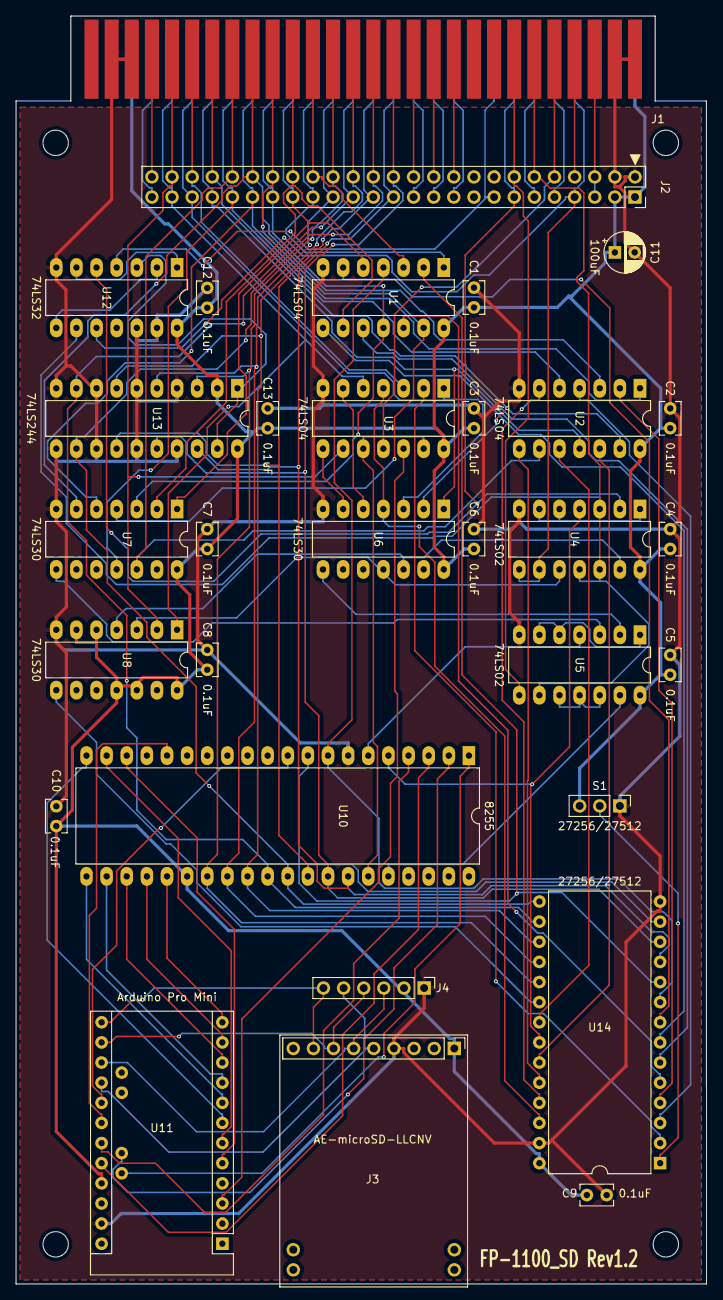
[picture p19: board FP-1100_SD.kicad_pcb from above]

Board: 2 copper layers, 87.1 x 160.0 mm, 35 parts (0 on the bottom side), 95 nets.

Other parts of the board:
MH1, MH2, MH3, MH4: MountingHole_3.2mm_M3

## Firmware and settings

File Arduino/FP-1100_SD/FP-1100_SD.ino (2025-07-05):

#include "SdFat.h"
#include <SPI.h>
SdFat SD;
char m_name[40];
char f_name[40];
char c_name[40];
char sdir[10][40];
File file_r,file_w;
byte f_length2,f_length1;
unsigned long r_count=0;
unsigned int f_length=0;

#define CABLESELECTPIN  (10)
#define CHKPIN          (15)
#define PB0PIN          (2)
#define PB1PIN          (3)
#define PB2PIN          (4)
#define PB3PIN          (5)
#define PB4PIN          (6)
#define PB5PIN          (7)
#define PB6PIN          (8)
#define PB7PIN          (9)
#define FLGPIN          (14)
#define PA0PIN          (16)
#define PA1PIN          (17)
#define PA2PIN          (18)
#define PA3PIN          (19)
// ファイル名は、ロングファイルネーム形式対応
boolean eflg;

void sdinit(void){
  // SD初期化
  if( !SD.begin(CABLESELECTPIN,8) )
  {
////    Serial.println("Failed : SD.begin");
    eflg = true;
  } else {
////    Serial.println("OK : SD.begin");
    eflg = false;
  }
////    Serial.println("START");
}

void setup(){
////  Serial.begin(9600);
// CS=pin10
// pin10 output

  pinMode(CABLESELECTPIN,OUTPUT);
  pinMode( CHKPIN,INPUT);  //CHK
  pinMode( PB0PIN,OUTPUT); //送信データ
  pinMode( PB1PIN,OUTPUT); //送信データ
  pinMode( PB2PIN,OUTPUT); //送信データ
  pinMode( PB3PIN,OUTPUT); //送信データ
  pinMode( PB4PIN,OUTPUT); //送信データ
  pinMode( PB5PIN,OUTPUT); //送信データ
  pinMode( PB6PIN,OUTPUT); //送信データ
  pinMode( PB7PIN,OUTPUT); //送信データ
  pinMode( FLGPIN,OUTPUT); //FLG

  pinMode( PA0PIN,INPUT_PULLUP); //受信データ
  pinMode( PA1PIN,INPUT_PULLUP); //受信データ
  pinMode( PA2PIN,INPUT_PULLUP); //受信データ
  pinMode( PA3PIN,INPUT_PULLUP); //受信データ

  digitalWrite(PB0PIN,LOW);
  digitalWrite(PB1PIN,LOW);
  digitalWrite(PB2PIN,LOW);
  digitalWrite(PB3PIN,LOW);
  digitalWrite(PB4PIN,LOW);
  digitalWrite(PB5PIN,LOW);
  digitalWrite(PB6PIN,LOW);
  digitalWrite(PB7PIN,LOW);
  digitalWrite(FLGPIN,LOW);

  sdinit();
}

//4BIT受信
byte rcv4bit(void){
//HIGHになるまでループ
  while(digitalRead(CHKPIN) != HIGH){
  }
//受信
  byte j_data = digitalRead(PA0PIN)+digitalRead(PA1PIN)*2+digitalRead(PA2PIN)*4+digitalRead(PA3PIN)*8;
//FLGをセット
  digitalWrite(FLGPIN,HIGH);
//LOWになるまでループ
  while(digitalRead(CHKPIN) == HIGH){
  }
//FLGをリセット
  digitalWrite(FLGPIN,LOW);
  return(j_data);
}

//1BYTE受信
byte rcv1byte(void){
  byte i_data = 0;
  i_data=rcv4bit()*16;
  i_data=i_data+rcv4bit();
  return(i_data);
}

//1BYTE送信
void snd1byte(byte i_data){
//下位ビットから8ビット分をセット
  digitalWrite(PB0PIN,(i_data)&0x01);
  digitalWrite(PB1PIN,(i_data>>1)&0x01);
  digitalWrite(PB2PIN,(i_data>>2)&0x01);
  digitalWrite(PB3PIN,(i_data>>3)&0x01);
  digitalWrite(PB4PIN,(i_data>>4)&0x01);
  digitalWrite(PB5PIN,(i_data>>5)&0x01);
  digitalWrite(PB6PIN,(i_data>>6)&0x01);
  digitalWrite(PB7PIN,(i_data>>7)&0x01);
  digitalWrite(FLGPIN,HIGH);
//HIGHになるまでループ
  while(digitalRead(CHKPIN) != HIGH){
  }
  digitalWrite(FLGPIN,LOW);
//LOWになるまでループ
  while(digitalRead(CHKPIN) == HIGH){
  }
}

//ファイル名の最後が「.bin」なら0,「.bas」なら1,どちらでもなければ0xFF
byte extchk(char *f_name){
  unsigned int lp1=0;
  byte r_data = 0xFF;
  while (f_name[lp1] != 0x00){
//    m_name[lp1] = f_name[lp1];
    lp1++;
  }
  if (f_name[lp1-4]=='.' &&
    ( f_name[lp1-3]=='B' ||
      f_name[lp1-3]=='b' ) &&
    ( f_name[lp1-2]=='I' ||
      f_name[lp1-2]=='i' ) &&
    ( f_name[lp1-1]=='N' ||
      f_name[lp1-1]=='n' ) ){
         r_data = 0;
  }
  if (f_name[lp1-4]=='.' &&
    ( f_name[lp1-3]=='B' ||
      f_name[lp1-3]=='b' ) &&
    ( f_name[lp1-2]=='A' ||
      f_name[lp1-2]=='a' ) &&
    ( f_name[lp1-1]=='S' ||
      f_name[lp1-1]=='s' ) ){
         r_data = 1;
  }
  if (f_name[lp1-4]=='.' &&
    ( f_name[lp1-3]=='F' ||
      f_name[lp1-3]=='f' ) &&
    ( f_name[lp1-2]=='P' ||
      f_name[lp1-2]=='p' ) &&
    ( f_name[lp1-1]=='T' ||
      f_name[lp1-1]=='t' ) ){
         r_data = 2;
  }
  return(r_data);
}

//ファイル名の最後が「.bin」でなければ付加
void addbin(char *f_name,char *m_name){
  unsigned int lp1=0;
  while (f_name[lp1] != 0x00){
    m_name[lp1] = f_name[lp1];
    lp1++;
  }
  if (f_name[lp1-4]!='.' ||
    ( f_name[lp1-3]!='B' &&
      f_name[lp1-3]!='b' ) ||
    ( f_name[lp1-2]!='I' &&
      f_name[lp1-2]!='i' ) ||
    ( f_name[lp1-1]!='N' &&
      f_name[lp1-1]!='n' ) ){
         m_name[lp1++] = '.';
         m_name[lp1++] = 'b';
         m_name[lp1++] = 'i';
         m_name[lp1++] = 'n';
  }
  m_name[lp1] = 0x00;
}

//ファイル名の最後が「.bas」でなければ付加
void addbas(char *f_name,char *m_name){
  unsigned int lp1=0;
  while (f_name[lp1] != 0x00){
    m_name[lp1] = f_name[lp1];
    lp1++;
  }
  if (f_name[lp1-4]!='.' ||
    ( f_name[lp1-3]!='B' &&
      f_name[lp1-3]!='b' ) ||
    ( f_name[lp1-2]!='A' &&
      f_name[lp1-2]!='a' ) ||
    ( f_name[lp1-1]!='S' &&
      f_name[lp1-1]!='s' ) ){
         m_name[lp1++] = '.';
         m_name[lp1++] = 'b';
         m_name[lp1++] = 'a';
         m_name[lp1++] = 's';
  }
  m_name[lp1] = 0x00;
}

//ファイル名の最後が「.fpt」でなければ付加
void addfpt(char *f_name,char *m_name){
  unsigned int lp1=0;
  while (f_name[lp1] != 0x00){
    m_name[lp1] = f_name[lp1];
    lp1++;
  }
  if (f_name[lp1-4]!='.' ||
    ( f_name[lp1-3]!='F' &&
      f_name[lp1-3]!='f' ) ||
    ( f_name[lp1-2]!='P' &&
      f_name[lp1-2]!='p' ) ||
    ( f_name[lp1-1]!='T' &&
      f_name[lp1-1]!='t' ) ){
         m_name[lp1++] = '.';
         m_name[lp1++] = 'f';
         m_name[lp1++] = 'p';
         m_name[lp1++] = 't';
  }
  m_name[lp1] = 0x00;
}

//比較文字列取得 32+1文字まで取得、ただしダブルコーテーションは無視する
void receive_name(char *f_name){
char r_data;
  unsigned int lp2 = 0;
  for (unsigned int lp1 = 0;lp1 <= 32;lp1++){
    r_data = rcv1byte();
    if (r_data != 0x22){
      f_name[lp2] = r_data;
      lp2++;
    }
  }
////  Serial.println(f_name);
}

//SDカードから機械語を読込
void fm_load(void){
  int wk1 = 0;
  unsigned int lp1;
//ファイルネーム取得
  receive_name(f_name);
  addbin(f_name,m_name);
////  Serial.println(m_name);
//ファイルが存在しなければERROR
  if (SD.exists(m_name) == true){
//ファイルオープン
    file_r = SD.open( m_name, FILE_READ );
    if( true == file_r ){
//状態コード送信(OK)
        snd1byte(0x00);

//ファイルサイズ取得
          f_length = file_r.size()-6;
          f_length2 = f_length % 256;
          f_length1 = f_length / 256;
          snd1byte(f_length2);
          snd1byte(f_length1);

//          if(rcv1byte()==0x00){
//データ送信
            wk1 = file_r.read();
            wk1 = file_r.read();
            if(f_length>0){
              for (lp1 = 1;lp1 <= f_length+4;lp1++){
                wk1 = file_r.read();
                snd1byte(wk1);
              }
//            }
          }
        file_r.close();
        sdinit();
     } else {
//状態コード送信(ERROR)
      snd1byte(0xFF);
      sdinit();
     }
   } else {
//状態コード送信(FILE NOT FIND ERROR)
    snd1byte(0xF1);
    sdinit();
  }
}

//SDカードからBASICプログラムを読込
void fb_load(void){
  int wk1 = 0;
  unsigned int lp1;
//ファイルネーム取得
  receive_name(f_name);
  addbas(f_name,m_name);
////  Serial.println(m_name);
//ファイルが存在しなければERROR
  if (SD.exists(m_name) == true){
//ファイルオープン
    file_r = SD.open( m_name, FILE_READ );
    if( true == file_r ){
//状態コード送信(OK)
        snd1byte(0x00);

//ファイルサイズ取得
          f_length = file_r.size();
          f_length2 = f_length % 256;
          f_length1 = f_length / 256;
          snd1byte(f_length2);
          snd1byte(f_length1);

          if(rcv1byte()==0x00){
//データ送信
            if(f_length>0){
              for (lp1 = 1;lp1 <= f_length;lp1++){
                wk1 = file_r.read();
                snd1byte(wk1);
              }
            }
          }
        file_r.close();
        sdinit();
     } else {
//状態コード送信(ERROR)
      snd1byte(0xFF);
      sdinit();
     }
   } else {
//状態コード送信(FILE NOT FIND ERROR)
    snd1byte(0xF1);
    sdinit();
  }
}

//load file set
void load_set(void){
  int wk1 = 0;
  unsigned int lp1;
//ファイルネーム取得
  receive_name(f_name);
  addfpt(f_name,m_name);
//ファイルが存在しなければERROR
  if (SD.exists(m_name) == true){
//ファイルオープン
    file_r = SD.open( m_name, FILE_READ );
    if( true == file_r ){
//状態コード送信(OK)
        snd1byte(0x00);

     } else {
//状態コード送信(ERROR)
      snd1byte(0xFF);
      sdinit();
     }
   } else {
//状態コード送信(FILE NOT FIND ERROR)
    snd1byte(0xF1);
    sdinit();
  }
}

//load1byte、OPENしているファイルの続きから1Byteを読み込み、送信
void load1byte(void){
  byte rdata;
  if (file_r == true){
    rdata = file_r.read();
    r_count++;
    snd1byte(rdata);
////  Serial.print("load:");
////  Serial.print(r_count);
////  Serial.print(":");
////  Serial.println(rdata,HEX);
//ファイルエンドまで達していればFILE CLOSE
      if (f_length == r_count){
        file_r.close();
      }
//    rdata = 0x00;
//    snd1byte(rdata);
//  }else{
//    rdata = 0xff;
//    snd1byte(rdata);
  }      
}

//SDカードにBASICプログラムを書き込み
void fb_save(void){
  int wk1 = 0;
  unsigned long lp1;
//ファイルネーム取得
  receive_name(f_name);
  addbas(f_name,m_name);
//
//ファイルが存在すればdelete
  if (SD.exists(m_name) == true){
    SD.remove(m_name);
  }
//ファイルオープン
  file_w = SD.open( m_name, FILE_WRITE );
  if( true == file_w ){
//状態コード送信(OK)
    snd1byte(0x00);
      f_length1 = rcv1byte();
      f_length2 = rcv1byte();
      f_length = f_length2*256+f_length1;

      if(f_length>0){
        for (lp1 = 1;lp1 <= f_length;lp1++){
          wk1 = rcv1byte();
          file_w.write(wk1);
        }
      }
    file_w.close();
  } else {
//状態コード送信(ERROR)
    snd1byte(0xF1);
    sdinit();
  }
}

//SDカードに機械語を書き込み
void fm_save(void){
  int wk1 = 0;
  unsigned int lp1,s_adrs,g_adrs;
  byte s_adrs1,s_adrs2,g_adrs1,g_adrs2;
//ファイルネーム取得
  receive_name(f_name);
  addbin(f_name,m_name);
//
//ファイルが存在すればdelete
  if (SD.exists(m_name) == true){
    SD.remove(m_name);
  }
//ファイルオープン
  file_w = SD.open( m_name, FILE_WRITE );
  if( true == file_w ){
//状態コード送信(OK)
    snd1byte(0x00);
      f_length1 = rcv1byte();
      f_length2 = rcv1byte();
      f_length = f_length2*256+f_length1;

      s_adrs1 = rcv1byte();
      s_adrs2 = rcv1byte();
      s_adrs = s_adrs2*256+s_adrs1;

      f_length = f_length-s_adrs+1;
      f_length2 = f_length / 256;
      f_length1 = f_length % 256;
      file_w.write(f_length1);
      file_w.write(f_length2);
      file_w.write(s_adrs1);
      file_w.write(s_adrs2);

      g_adrs1 = rcv1byte();
      g_adrs2 = rcv1byte();
      g_adrs = g_adrs2*256+g_adrs1;
      file_w.write(g_adrs1);
      file_w.write(g_adrs2);
      
      if(f_length>0){
        for (lp1 = 1;lp1 <= f_length;lp1++){
          wk1 = rcv1byte();
          file_w.write(wk1);
        }
      }
    file_w.close();
  } else {
//状態コード送信(ERROR)
    snd1byte(0xF1);
    sdinit();
  }
}

//f_nameとc_nameをc_nameに0x00が出るまで比較
//FILENAME COMPARE
boolean f_match(char *f_name,char *c_name){
  boolean flg1 = true;
  unsigned int lp1 = 0;
  while (lp1 <=32 && c_name[0] != 0x00 && flg1 == true){
    if (upper(f_name[lp1]) != upper(c_name[lp1])){
      flg1 = false;
    }
    lp1++;
    if (c_name[lp1]==0x00){
      break;
    }
  }
  return flg1;
}

//小文字->大文字
char upper(char c){
  if('a' <= c && c <= 'z'){
    c = c - ('a' - 'A');
  }
  return c;
}


// SD-CARDのFILELIST
void dirlist(void){
  byte extflg;
//比較文字列取得 32+1文字まで
  receive_name(c_name);
  File file2 = SD.open( "/" );
  if( file2 == true ){
//状態コード送信(OK)
    snd1byte(0x00);
   File entry =  file2.openNextFile();
    int cntl2 = 0;
    unsigned int br_chk =0;
    int page = 1;
//全件出力の場合には10件出力したところで一時停止、キー入力により継続、打ち切りを選択
    while (br_chk == 0) {
      if(entry){
        entry.getName(f_name,36);
        unsigned int lp1=0;
//一件送信
//比較文字列でファイルネームを先頭から比較して一致するものだけを出力
        if (f_match(f_name,c_name)){
//sdir[]にf_nameを保存
          strcpy(sdir[cntl2],f_name);
          snd1byte(0x30+cntl2);
          snd1byte(0x20);
          while (lp1<=36 && f_name[lp1]!=0x00){
            snd1byte(f_name[lp1]);
            lp1++;
          }
          snd1byte(0x00);
          cntl2++;
        }
      }
// CNTL2 > 表示件数-1
      if (!entry || cntl2 > 9){
//継続・打ち切り選択指示要求
        snd1byte(0xfe);

//選択指示受信(0:継続 B:前ページ 以外:打ち切り)
        br_chk = rcv1byte();
//前ページ処理
        if (br_chk==0x42){
//先頭ファイルへ
          file2.rewindDirectory();
//entry値更新
          entry =  file2.openNextFile();
//もう一度先頭ファイルへ
          file2.rewindDirectory();
          if(page <= 2){
//現在ページが1ページ又は2ページなら1ページ目に戻る処理
            page = 0;
          } else {
//現在ページが3ページ以降なら前々ページまでのファイルを読み飛ばす
            page = page -2;
            cntl2=0;
//page*表示件数
            while(cntl2 < page*10){
                entry =  file2.openNextFile();
                if (f_match(f_name,c_name)){
                  cntl2++;
                }
            }
         }
          br_chk=0;
        }
//1～0までの数字キーが押されたらsdir[]から該当するファイル名を送信
        if(br_chk>=0x30 && br_chk<=0x39){
          file_r = SD.open( sdir[br_chk-0x30], FILE_READ );
          if( file_r == true ){
            extflg = extchk(sdir[br_chk-0x30]);
            unsigned int lp2=0;
            snd1byte(0xFD);
            while (lp2<=36 && sdir[br_chk-0x30][lp2]!=0x00){
              snd1byte(sdir[br_chk-0x30][lp2]);
              lp2++;
            }
            snd1byte(0x00);
            file_r.close();
          }
        }
        page++;
        cntl2 = 0;
      }
//ファイルがまだあるなら次読み込み、なければ打ち切り指示
      if (entry){
        entry =  file2.openNextFile();
      }else{
        br_chk=1;
      }
    }
//処理終了指示
    snd1byte(0xFF);
    snd1byte(0x00);
    snd1byte(extflg);
  }else{
    snd1byte(0xf1);
  }
}

void loop()
{
  digitalWrite(PB2PIN,LOW);
  digitalWrite(PB3PIN,LOW);
  digitalWrite(FLGPIN,LOW);
//コマンド取得待ち
////  Serial.print("cmd:");
  byte cmd = rcv1byte();
////  Serial.println(cmd,HEX);
  if (eflg == false){
    switch(cmd) {
//17hでSDカードからBinary Load
      case 0x17:
//状態コード送信(OK)
////  Serial.println("BINARY LOAD START");
//状態コード送信(OK)
        snd1byte(0x00);
        fm_load();
        break;
//18hでSDカードからBASIC Program Load
      case 0x18:
//状態コード送信(OK)
////  Serial.println("BASIC LOAD START");
//状態コード送信(OK)
        snd1byte(0x00);
        fb_load();
        break;
//13hでSDカードにBinary save
      case 0x13:
//状態コード送信(OK)
////  Serial.println("Binary SAVE START");
//状態コード送信(OK)
        snd1byte(0x00);
        fm_save();
        break;
//14hでSDカードにBASIC Program save
      case 0x14:
//状態コード送信(OK)
////  Serial.println("BASIC Program SAVE START");
//状態コード送信(OK)
        snd1byte(0x00);
        fb_save();
        break;
//11hでSDカードファイル一覧
      case 0x11:
//状態コード送信(OK)
////  Serial.println("SD DIR START");
//状態コード送信(OK)
        snd1byte(0x00);
        sdinit();
        dirlist();
        break;
//15hでLoad set
      case 0x15:
//状態コード送信(OK)
////  Serial.println("LOAD SET");
//状態コード送信(OK)
        snd1byte(0x00);
        load_set();
        break;
//16hでLOAD1BYTE
      case 0x16:
////    Serial.println("LOAD1BYTE");
//状態コード送信(OK)
        if(file_r == true){
          snd1byte(0x00);
          load1byte();
        } else{
////    Serial.println("LOAD FILE NOT OPEN");
          snd1byte(0xff);
        }
        break;
      default:
//状態コード送信(CMD ERROR)
        snd1byte(0xF4);
    }
  } else {
//状態コード送信(ERROR)
    snd1byte(0xF0);
// コマンド11hの場合だけextchkの値待ちになるので仮の値0xFFを送信
    if (cmd == 0x11){
      snd1byte(0xFF);
    }
    sdinit();
  }
}
